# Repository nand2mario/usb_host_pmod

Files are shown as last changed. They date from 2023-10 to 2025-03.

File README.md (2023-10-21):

# USB Host PMOD

Design sources for a **dual-socket USB host PMOD** module, intended for interfacing USB devices on FPGA boards using [usb_hid_host](https://github.com/nand2mario/usb_hid_host). 

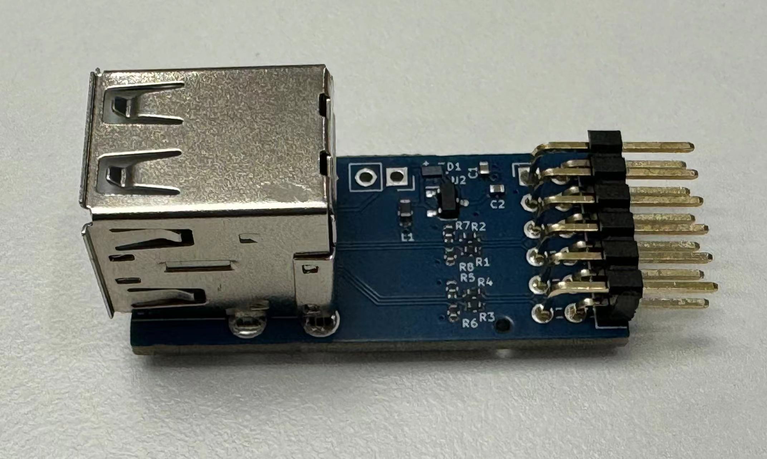
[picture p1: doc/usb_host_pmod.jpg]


Included are [KiCAD sources](kicad/) and [production files](production/)(Gerber/BOM/PNP).

The easiest way to obtain the module is by following the [guide to directly order from JLCPCB](doc/guide.md).

This little design is done by [@regymm0](https://twitter.com/regymm0), [@ico_TC](https://twitter.com/ico_TC) and [@nand2mario](https://twitter.com/nand2mario).

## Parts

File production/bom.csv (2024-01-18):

Designator | Footprint | Quantity | Value | LCSC Part #
C1, C2 | 0402 | 2 | 10uF | C15525
D1 | 0402 | 1 | 1N5817/1N5819/1N5822 | C145508
J1 | USB_A_Wuerth_61400826021_Horizontal_Stacked | 1 | USB_A_Stacked | C698206
J2 | PinHeader_2x06_P2.54mm_Horizontal | 1 | Conn_02x06_Odd_Even | C492434
J3 | PinSocket_1x02_P2.54mm_Vertical | 1 | Conn_01x02_Socket | NC
L1 | 0603 | 1 | 10uH | C1035
R1, R2, R3, R4 | 0402 | 4 | 22 | C25092
R5, R6, R7, R8 | 0402 | 4 | 15K | C25756
U2 | SOT-23 | 1 | QX2303L50T | C219027

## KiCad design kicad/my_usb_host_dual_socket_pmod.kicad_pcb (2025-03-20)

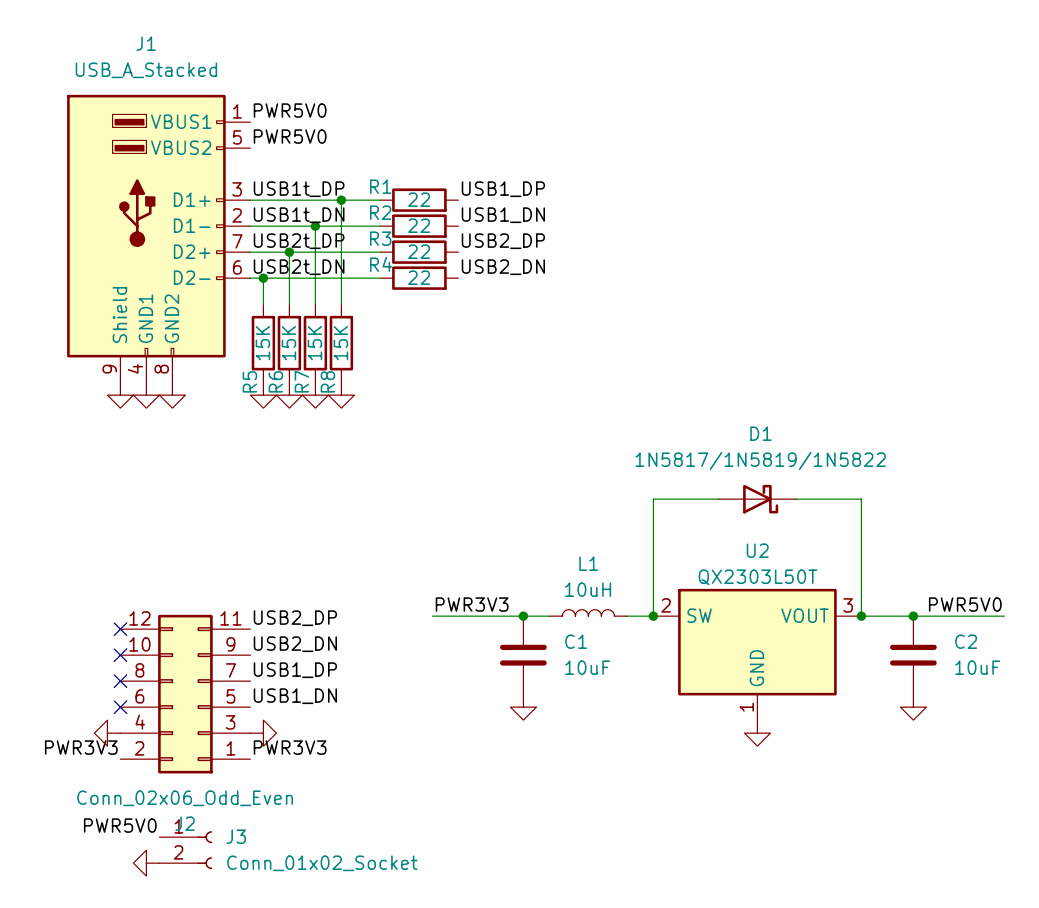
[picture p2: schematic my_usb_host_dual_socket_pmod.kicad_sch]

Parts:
C1, C2: 10uF; C_0402_1005Metric
D1: 1N5817/1N5819/1N5822; D_0402_1005Metric
J1: USB_A_Stacked; USB_A_Wuerth_61400826021_Horizontal_Stacked
J2: Conn_02x06_Odd_Even; PinHeader_2x06_P2.54mm_Horizontal
J3: Conn_01x02_Socket; PinSocket_1x02_P2.54mm_Vertical
L1: 10uH; L_0603_1608Metric
R1, R2, R3, R4: 22; R_0402_1005Metric
R5, R6, R7, R8: 15K; R_0402_1005Metric
U2: QX2303L50T; SOT-23

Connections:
/PWR3V3: C1.1, J2.1, J2.2, L1.1
/PWR5V0: C2.1, D1.1 (K), J1.1 (VBUS1), J1.5 (VBUS2), J3.1, U2.3 (VOUT)
/USB1_DN: J2.5, R2.2
/USB1_DP: J2.7, R1.2
/USB1t_DN: J1.2 (D1-), R2.1, R7.2
/USB1t_DP: J1.3 (D1+), R1.1, R8.2
/USB2_DN: J2.9, R4.2
/USB2_DP: J2.11, R3.2
/USB2t_DN: J1.6 (D2-), R4.1, R5.2
/USB2t_DP: J1.7 (D2+), R3.1, R6.2
GND: C1.2, C2.2, J1.4 (GND1), J1.8 (GND2), J1.9 (Shield), J2.3, J2.4, J3.2, R5.1, R6.1, R7.1, R8.1, U2.1 (GND)
unnamed: D1.2 (A), L1.2, U2.2 (SW)

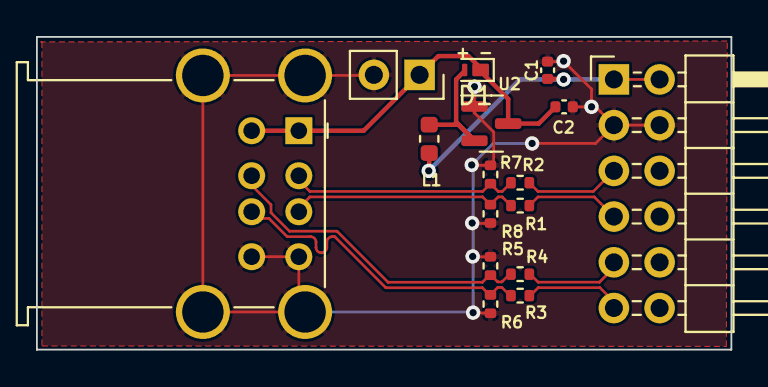
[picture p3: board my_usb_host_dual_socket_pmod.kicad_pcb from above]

Board: 2 copper layers, 38.6 x 17.4 mm, 16 parts (0 on the bottom side), 12 nets.

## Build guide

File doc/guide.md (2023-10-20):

# JLCPCB Ordering Guide

This is the steps to have the PCB manufactured and components assembled by JLCPCB. 5 modules cost ~$28 plus shipping. 10 modules cost ~$34 plus shipping.

1. Clone or [download](https://github.com/nand2mario/usb_host_pmod/archive/master.zip) the USB Host PMOD repository.

2. Create an account with [JLCPCB.com](http://JLCPCB.com).

3. Go to: [https://cart.jlcpcb.com/quote](https://cart.jlcpcb.com/quote)

4. Click the `Add gerber file` button and select [usb_host_pmod.zip](../production/usb_host_pmod.zip).

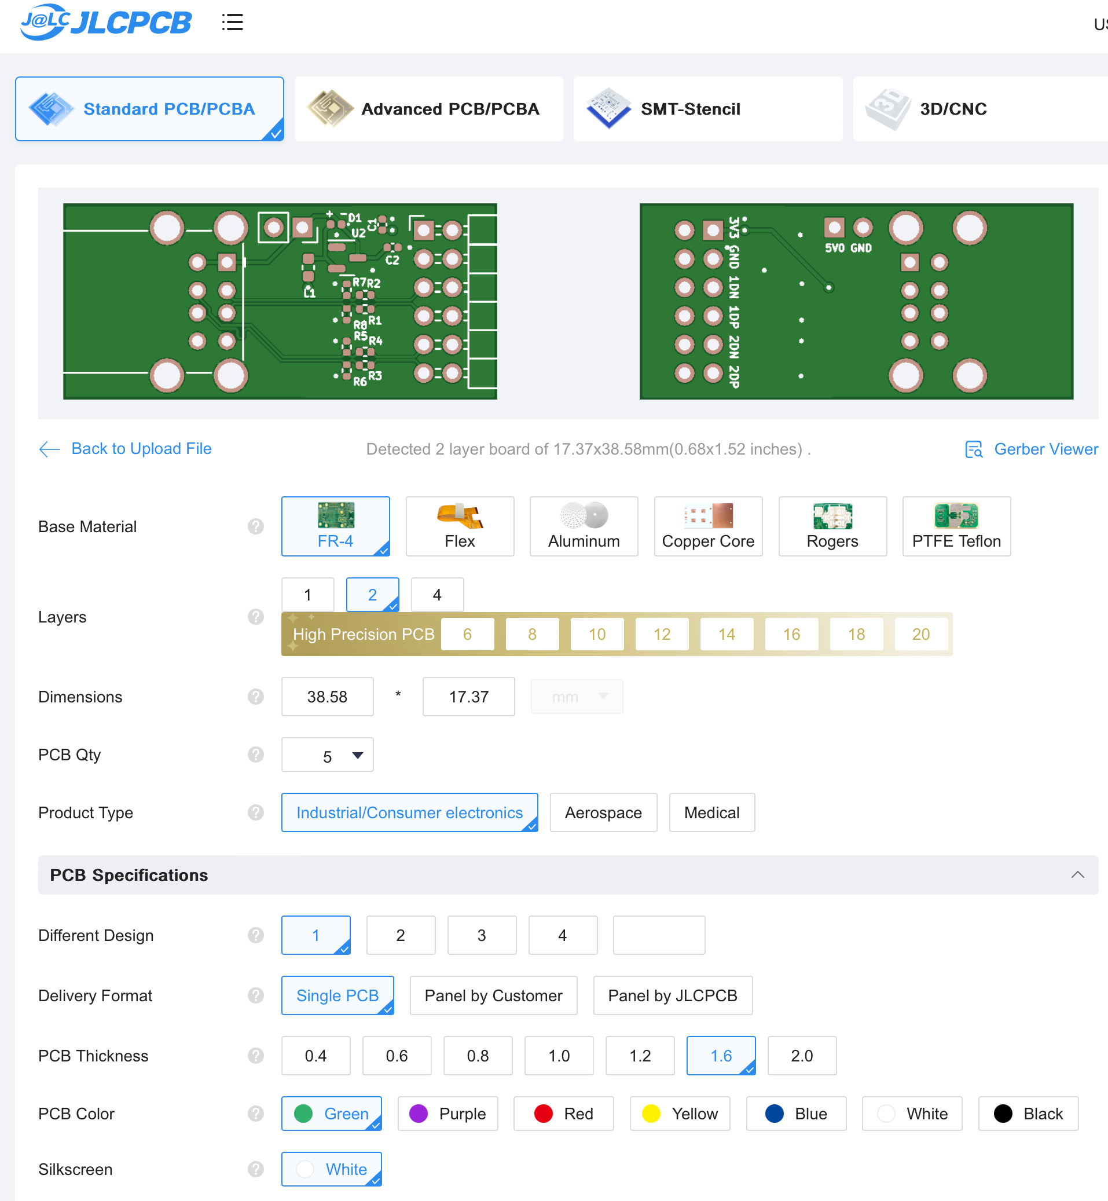
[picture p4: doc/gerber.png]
5. You should now see the PCB front and back in the preview 

6. There are a few properties that you can customize if you want. The PCB quantity (the amount you want made), thickness, color, and surface finish are all I recommend adjusting to preference.

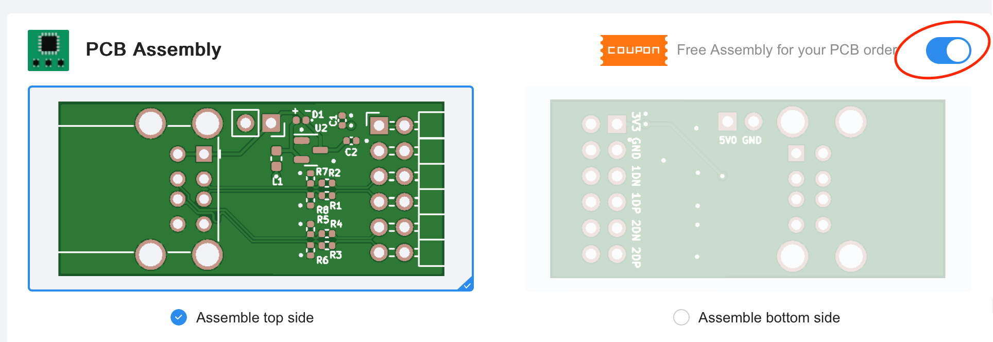
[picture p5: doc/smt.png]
7. Select the toggle button to enable SMT Assembly 

8. Select the `Assemble top side` option

9. Select how many boards you want assembled with the `PCBa Qty` option

10. Select the `confirm` and then `Next` button to continue

11. Upload the [bom.csv](../production/bom.csv) and [positions.csv](../../positions.csv) files on the Bill of Materials page. Then click "Process BOM & CPL" to proceed.

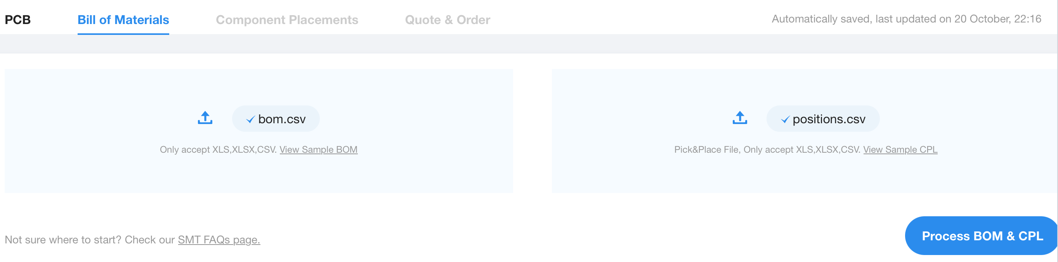
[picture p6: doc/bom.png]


12. Click "Next" again on the Bill of Materials page. Click "do not place" on the popup dialog, as we do not need the J3 pin placed.

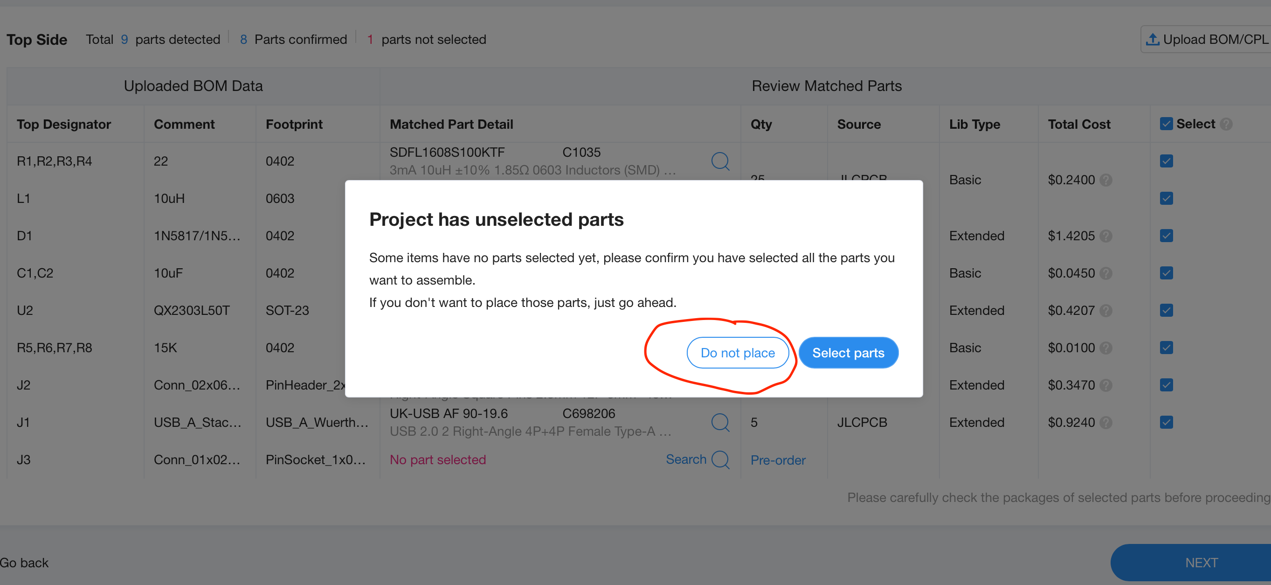
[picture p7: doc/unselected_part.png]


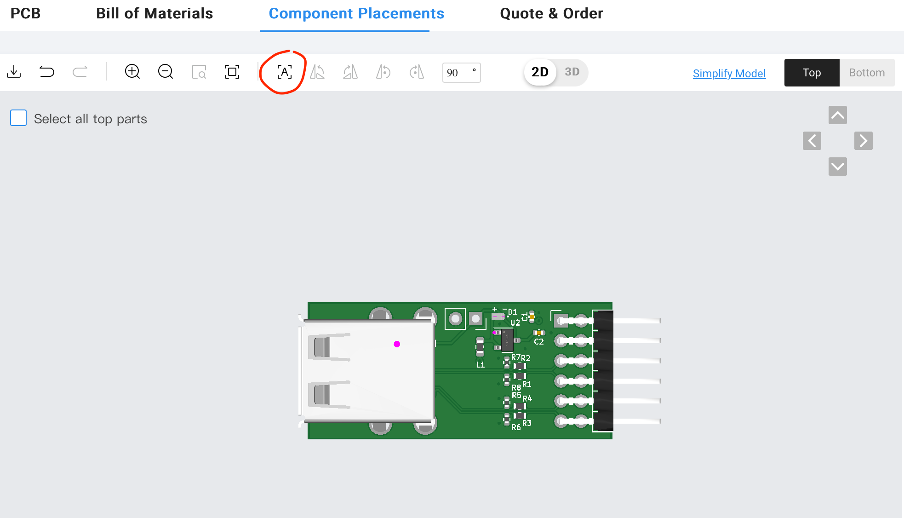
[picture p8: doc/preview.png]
13. You should now see a preview of the parts placement on the PCB. The placement of some components will appear wrongly placed. **This is ok.** Just press the "align" (marked with an "A") button on the toolbar and it will be fixed. 

14. Click "Next" again and you will see the price quote. Here you can place the order in the cart and on the next page, you can check out.

*This page is based on [Cheap-FOCer-2 ordering guide](https://github.com/shamansystems/Cheap-FOCer-2/blob/master/guides/ordering/readme.md)*

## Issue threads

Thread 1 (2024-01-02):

JLCPCB Ordering Guide step 13 not working as described

mcclure, 2024-01-02:
Hello, I am interested in getting some USB ports to attach to a colorlight board. I am following your instructions on ordering from JLPCB:

https://github.com/nand2mario/usb_host_pmod/blob/main/doc/guide.md

The steps up to 13 all worked and produced forms that looked like the ones in your screenshots.

But when I get to step 13, it does not behave like in the instructions. Step 13 says: "The placement of some components will appear wrongly placed. This is ok. Just press the "align" (marked with an "A") button on the toolbar and it will be fixed." I interpret this to mean that it is fine for the components to *initially* appear wrongly, but I assume they need to be correctly placed *before proceeding*.

This is what i see on initially loading the pane

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

However, if I click "Align" it does not fix it. I can press "Align" multiple times and each time it snaps to a different incorrect-looking position.

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

It says the preview is "for reference only". Is it okay to proceed from this point if the preview still looks wrong *even after pressing the "Align" button?*

Thanks.

nand2mario, 2024-01-10:
JLC probably changed their "align" function somehow. It use to work just fine. To be sure you can move and rotate the usb socket and pins to the correct locations. These two are manually assembled. So I believe some inaccuracies on your side should be fine.

mcclure, 2024-01-15:
Based on your comment I moved all the pieces in place to a close visual match of the diagram in the ordering guide. (This turned out to not be hard.) When the part arrives I will report back whether it arrived as expected.

I think you should consider altering step 13 in your guide to note that if the align button does not seem to work, then you suggest manually dragging the pieces in the table one by one to fit the picture. If you do not feel this is necessary, you may close this issue.

Thank you for the help.

mcclure, 2024-01-16:
Hmm, unfortunately it appeared eyeballing it did not work out so well after all :(

Last night I got back an email from JLCPCB:

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

Can you give me any advice on how to proceed?

mcclure, 2024-01-17:
I spoke to a friend. They looked at the email and the git repo and concluded the part number C1035 for R1,R2,R3,R4 (bom.csv line 8) is incorrect (possibly accidentally duplicated from line 7) and the part number there should be something like C25092 (a 22 ohm 0402 resistor which is in the parts library [here](https://jlcpcb.com/partdetail/25835-0402WGF220JTCE/C25092)). So I think I want to go with "option A" (replace part, and swap out R1,R2,R3,R4 for C25092). Does this sound correct to you?

nand2mario, 2024-01-18:
C25092 is the correct part number. Not sure how it got mixed up.

Thanks for catching this.

mcclure, 2024-01-18:
Okay great, thanks for confirming. And I guess don't thank me thank Tavy :)

I have replaced the part in the order and production has resumed.

mcclure, 2024-01-19:
To update, after re-submitting to JLCPCB they sent it back again with this note…

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

From the wording ("can't"), this doesn't sound like an incorrect placement issue. Could there be another incorrect part number?

mcclure, 2024-01-31:
My friend Tavy who helped with the incorrect part before took a look at this. This is what they concluded:

D1 has a footprint for a 0402 diode, but the part selected (the C145508) is a "DSN-2" package. They believe the correct way to fix this is to fix the original CAD files so that D1 is sized for a DSN-2. They said that a [C907849](https://jlcpcb.com/partdetail/TechPublic-TPB4010ESB/C907849) could be substituted and fit, but that *that* part is rated for 1A not 2A so it's not totally clear it's a proper substitute. They also said that in a home assembly one could probably just force the C145508 to fit in the 0402-sized D1, and that looking at your photos they believe this is what you did in your existing builds, but they believe the size mismatch could introduce risks like shorting even aside from the fact that JLCPCB is balking at assembling it so it's worth fixing anyway.

Does this sound right to you ? Do the input gerber files need to be corrected?

regymm, 2024-02-02:
Hi, I'm the designer of this PCB, but I haven't actually tried submitting the design.

Usually, there're might be a constant offset that can be corrected by JLCPCB, but here it might be too few components to correctly detect.
Also, each component's footprint has their own reference point(the origin point when you open a component in KiCADFootprint Editor), for SMT components this is kinda universal(for 0402-like Cs and Rs, it's the middle point). But through-hole components, especially connectors like the USB, it's very common to have a reference point different from JLCPCB's model, and it'll appear off and shifted, it's impossible for auto-alignment to correct this.

So I usually need to rotate the component if necessary, and drag the component to the correct position. This is the same thing that causes some ICs and diodes to be mounted reversed if not careful.

About the overall shift, it's not recommended to drag-and-move each 0402 by hand. You can try the "Place origin point for drill files and component placement files", and place the origin at bottom-left corner of the board.
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
And then tweak the "Use drill/place file origin" option when generating placement files.

If this won't work, you can select all components on JLCPCB's interface(I think there's such a function), and manually move so that the SMT parts are aligned. Then manually align the THT parts.

I've used 0603 components on 0805 hand-solder footprints on JLC and there's just a warning and nothing's wrong with assembly, but maybe in the diode case it's too much...

mcclure, 2024-02-21:
@regymm , thanks, please excuse my limited knowledge on this subject. I'm not sure I've properly communicated what's happening…

> Usually, there're might be a constant offset that can be corrected by JLCPCB, but here it might be too few components to correctly detect… If this won't work, you can select all components on JLCPCB's interface(I think there's such a function), and manually move so that the SMT parts are aligned. Then manually align the THT parts.

There are two layers of problem using the JLCPCB flow. The first is that the automatic part placement panics and strews the parts all over (probably because, due to the R1-R4 and D1 errors in the repo's production files, the parts really truly do not fit). You are correct that I can manually move the parts in a JLCPCB web interface, and I did this, but this web interface is *very* imprecise.

The second layer of problem comes after manually placing parts and submitting the order. JLCPCB refuses to actually build it due to the non-fitting parts. In the case of R1-R4 this is because bom.csv was wrong; the R1-R4 problems are now fixed in git (although only in the .kicad_pcb, not in the production/ directory) and with my JLCPCB order I was able to simply tell them to substitute the wrong part for a right one. So that was straightforward. But after that was addressed they again declined to build, because of the separate issue with D1. In this case the bom.csv part is correct but the footprint for it on the board appears to be incorrect, and this they can't just swap out, the pcb will need to be changed.

> I've used 0603 components on 0805 hand-solder footprints on JLC and there's just a warning and nothing's wrong with assembly, but maybe in the diode case it's too much...

When I search Google, I do find that the DSN1 footprint supposedly is a different size from the 0402 ones. If you tell me it will fit and it's fine that's one thing, but what both JLCPCB and my friend Tavy are telling me is that when it works it works with the risk of shorts. So I would prefer to fix it proper rather than asking JLCPCB to just ignore the size mismatch and solder it anyway.

Tavy graciously went into kicad and made a modded kicad_pcb with a changed footprint for D1. I have added this as a PR: https://github.com/nand2mario/usb_host_pmod/pull/2

Unfortunately, I don't know enough to confirm her work, and moreover I don't know enough to create "production" files from the kicad project :( So, I cannot submit this modded kicad_pcb to try it unless either I learn kicad (maybe not a bad idea) or one of y'all does whatever generation step you used to create the gerber, bom.csv and positions.csv files last time…

regymm, 2024-02-21:
Hi, thanks for your feedback, I recorded a video for JLCPCB demonstration (please ignore the first 10 seconds of uploading files).

https://www.youtube.com/watch?v=vbSGLDT_DI0

About the diode footprint: it's selected wrong by default, but as in the video, you can search and replace it with a normal 0402 footprint diode (that is in stock) and the warning will be gone. Thanks Tavy for the mod, but I think it'll be cool to keep both of the versions available, I'll probably change that commit into a new branch.

Then I demonstrated the part alignment, the auto-alignment works if you press the button many times... or just select all parts and drag them. As I mentioned before it's common to have through-hole components aligned off, that's because of the footprint model difference between kicad and JLC and can't be avoided. Personally I didn't notice web interface issues, and go to the payment scene without a problem.

Please let me know if there's anything else I can help!

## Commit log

2024-01-18 fix 22 ohm resistor part number
    [bom.csv]
2024-02-16 Replacement kicad_pcb supplied by Tavy
    Replaces D1 (0402 sized) with C907849 part (DSN-2 sized)
    [my_usb_host_dual_socket_pmod.kicad_pcb]
